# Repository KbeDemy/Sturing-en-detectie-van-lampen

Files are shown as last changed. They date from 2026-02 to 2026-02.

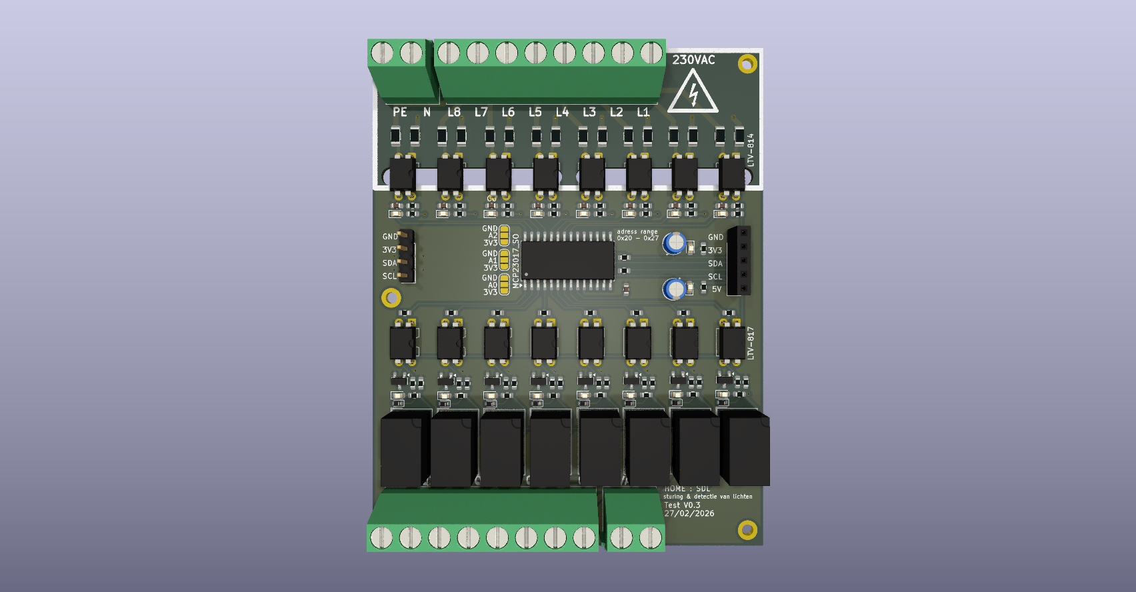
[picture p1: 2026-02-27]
documentation/screenshots/Schermafbeelding 2026-02-27 190239.png

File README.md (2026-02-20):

# I2C Uitbreiding bord - Lamp sturing & Detectie

Expansion board voor lampenbeheer. Bedoeld voor gebruik met een externe microcontroller (ESP32) via I2C.

## Specificaties
- **I/O Expander:** MCP23017 (I2C) 
- **Input:** 230V AC detectie via LTV-814 optocouplers.
- **Output:** 30V AC sturing voor Eltako relais via Omron G5V-1 relais.
- **Indicatie:** Debug-LED's voor logica en relaisstatus.

## Pinout & Adressen
- **I2C Adres:** Standaard 0x20 (instelbaar via A0, A1, A2).
- **Signaal/voeding - niveaus:** 
    - 3.3VDC logic
    - 5VDC aansturen relais
    - 30VAC aansturen eltako
    - 230VAC uitlezen status lamp
- **MCP GPA 0-7:** INPUT
- **MCP GPB 0-7:** OUTPUT

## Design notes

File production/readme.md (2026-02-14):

# Productiebestanden (JLCPCB)

* **Base Material:** FR-4
* **Layers:** 2
* **PCB Thickness:** 1.6 mm
* **Copper Weight:** 1 oz
* **Surface Finish:** HASL (met lood)

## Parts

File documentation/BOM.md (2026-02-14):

# Bill of Materials (BOM)

Hieronder staat de lijst met componenten die nodig zijn voor de assemblage van de PCB. De LCSC-codes verwijzen direct naar de onderdelen om ze makkelijk te bestellen.

| Onderdeel | Waarde / Beschrijving | Behuizing | LCSC Code | Datasheet |
| :--- | :--- | :--- | :--- | :--- |
| **IC's & Actief** | | | | |
| MCP23017-E/SO | I/O Expander 16-bit I2C | SOIC-28 | `C47023` | [PDF](https://www.lcsc.com/datasheet/C47023.pdf) |
| MMBT5551 | NPN Transistor (High Voltage) | SOT-23 | `C2977363` | [PDF](https://www.lcsc.com/datasheet/C2977363.pdf) |
| LTV-817-B | Optoisolator 5kV 1-Channel | DIP-4 | `C479627` | [PDF](https://www.lcsc.com/datasheet/C479627.pdf) |
| Phototransistor | Output 5kVrms 1 Channel | DIP-4 | `C10790` | [PDF](https://www.lcsc.com/datasheet/C10790.pdf) |
| **Relais & Connectoren** | | | | |
| G5V-1-DC5 | Relais SPDT 5V DC | THT | `C28695` | [PDF](https://www.lcsc.com/datasheet/C28695.pdf) |
| Screw Terminal | 2-Pin 5.08mm Horizontal | THT | `C480516` | [PDF](https://www.lcsc.com/datasheet/C480516.pdf) |
| Screw Terminal | 8-Pin 5.08mm Horizontal | THT | `C7165039` | [PDF](https://www.lcsc.com/datasheet/C7165039.pdf) |
| **Diodes & LEDs** | | | | |
| 1N4148WT | Schakeldiode 75V 150mA | SOD-523 | `C917006` | [PDF](https://www.lcsc.com/datasheet/C917006.pdf) |
| XL-1608SURC-06 | LED Rood 625nm | 0603 | `C965799` | [PDF](https://www.lcsc.com/datasheet/C965799.pdf) |
| **Condensatoren** | | | | |
| 100nF (0.1µF) | 50V X7R ±10% | 0603 | `C14663` | [PDF](https://www.lcsc.com/datasheet/C14663.pdf) |
| 470nF (0.47µF) | 50V X7R ±10% | 0603 | `C513577` | [PDF](https://www.lcsc.com/datasheet/C513577.pdf) |
| **Weerstanden** | | | | |
| 470Ω | ±1% 100mW | 0603 | `C23179` | [PDF](https://www.lcsc.com/datasheet/C23179.pdf) |
| 1kΩ | ±1% 100mW | 0603 | `C22548` | [PDF](https://www.lcsc.com/datasheet/C22548.pdf) |
| 4.7kΩ | ±5% 100mW | 0603 | `C2907166` | [PDF](https://www.lcsc.com/datasheet/C2907166.pdf) |
| 10kΩ | ±1% 100mW | 0603 | `C98220` | [PDF](https://www.lcsc.com/datasheet/C98220.pdf) |
| 100kΩ (HV) | 200V 500mW (Let op: Groot formaat!) | **1206** | `C309584` | [PDF](https://www.lcsc.com/datasheet/C309584.pdf) |

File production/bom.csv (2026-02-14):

Designator | Footprint | Quantity | Value | LCSC Part #
C1, C2, C3, C4, C5, C6, C7, C8 | 0603 | 8 | 0.47µ | CC0603KRX7R9BB474
C10, C11 | CP_Radial_D4.0mm_P1.50mm | 2 | 100µF
C100 | 0603 | 1 | 0.1µ | CC0603KRX7R9BB104
D1, D10, D11, D13, D15, D17, D19, D2, D21, D23, D25, D26, D3, D4, D5, D6, D7, D8 | 0603 | 18 | LED | XL-1608SURC-06
D12, D14, D16, D18, D20, D22, D24, D9 | D_SOD-523 | 8 | 1N4148 | 1N4148WT
GITHUB | https___github.com_KbeDemy_Sturing-en-detectie-van-lampen | 1 | DOCS
J0 | PinSocket_1x05_P2.54mm_Vertical | 1 | Conn_01x05
J1, J4 | TerminalBlock_Phoenix_MKDS-1,5-2-5.08_1x02_P5.08mm_Horizontal | 2 | Screw_Terminal_01x02 | 1715721
J2, J3 | TerminalBlock_Phoenix_MKDS-1,5-8-5.08_1x08_P5.08mm_Horizontal | 2 | Screw_Terminal_01x08 | 1715789
J5 | PinHeader_1x04_P2.54mm_Vertical | 1 | Conn_01x04
K1, K2, K3, K4, K5, K6, K7, K8 | Relay_SPDT_Omron_G5V-1 | 8 | G5V-1 | G5V-1-DC5
Q1, Q2, Q3, Q4, Q5, Q6, Q7, Q8 | SOT-23 | 8 | NPN | MMBT5551
R1, R10, R13, R14, R17, R18, R2, R21, R22, R25, R26, R29, R30, R5, R6, R9 | 1206 | 16 | 100k | RC1206FR-7W100KL
R11, R15, R19, R23, R27, R3, R31, R34, R40, R44, R48, R52, R56, R60, R64, R7 | 0603 | 16 | 10k | RC0603FR-0710KL
R12, R16, R20, R24, R28, R32, R35, R36, R37, R38, R4, R41, R42, R45, R46, R49, R50, R53, R54, R57, R58, R61, R62, R66, R67, R8 | 0603 | 26 | 470 | 0603WAF4700T5E
R33, R39, R43, R47, R51, R55, R59, R63 | 0603 | 8 | 1k | RC0603FR-071KL
R65, R68 | 0603 | 2 | 4.7k | FRC0603J472 TS
U1, U3, U4, U6, U7, U8, U9 | DIP-4_W7.62mm | 7 | LTV-814 | LITEON LTV-814
U11, U12, U13, U14, U15, U16, U17, U18 | DIP-4_W7.62mm | 8 | LTV-817 | LTV-817-B
U2 | SOIC-28W_7.5x17.9mm_P1.27mm | 1 | MCP23017_SO | MCP23017-E/SO
U5 | DIP-4_W7.62mm | 1 | LTV-814

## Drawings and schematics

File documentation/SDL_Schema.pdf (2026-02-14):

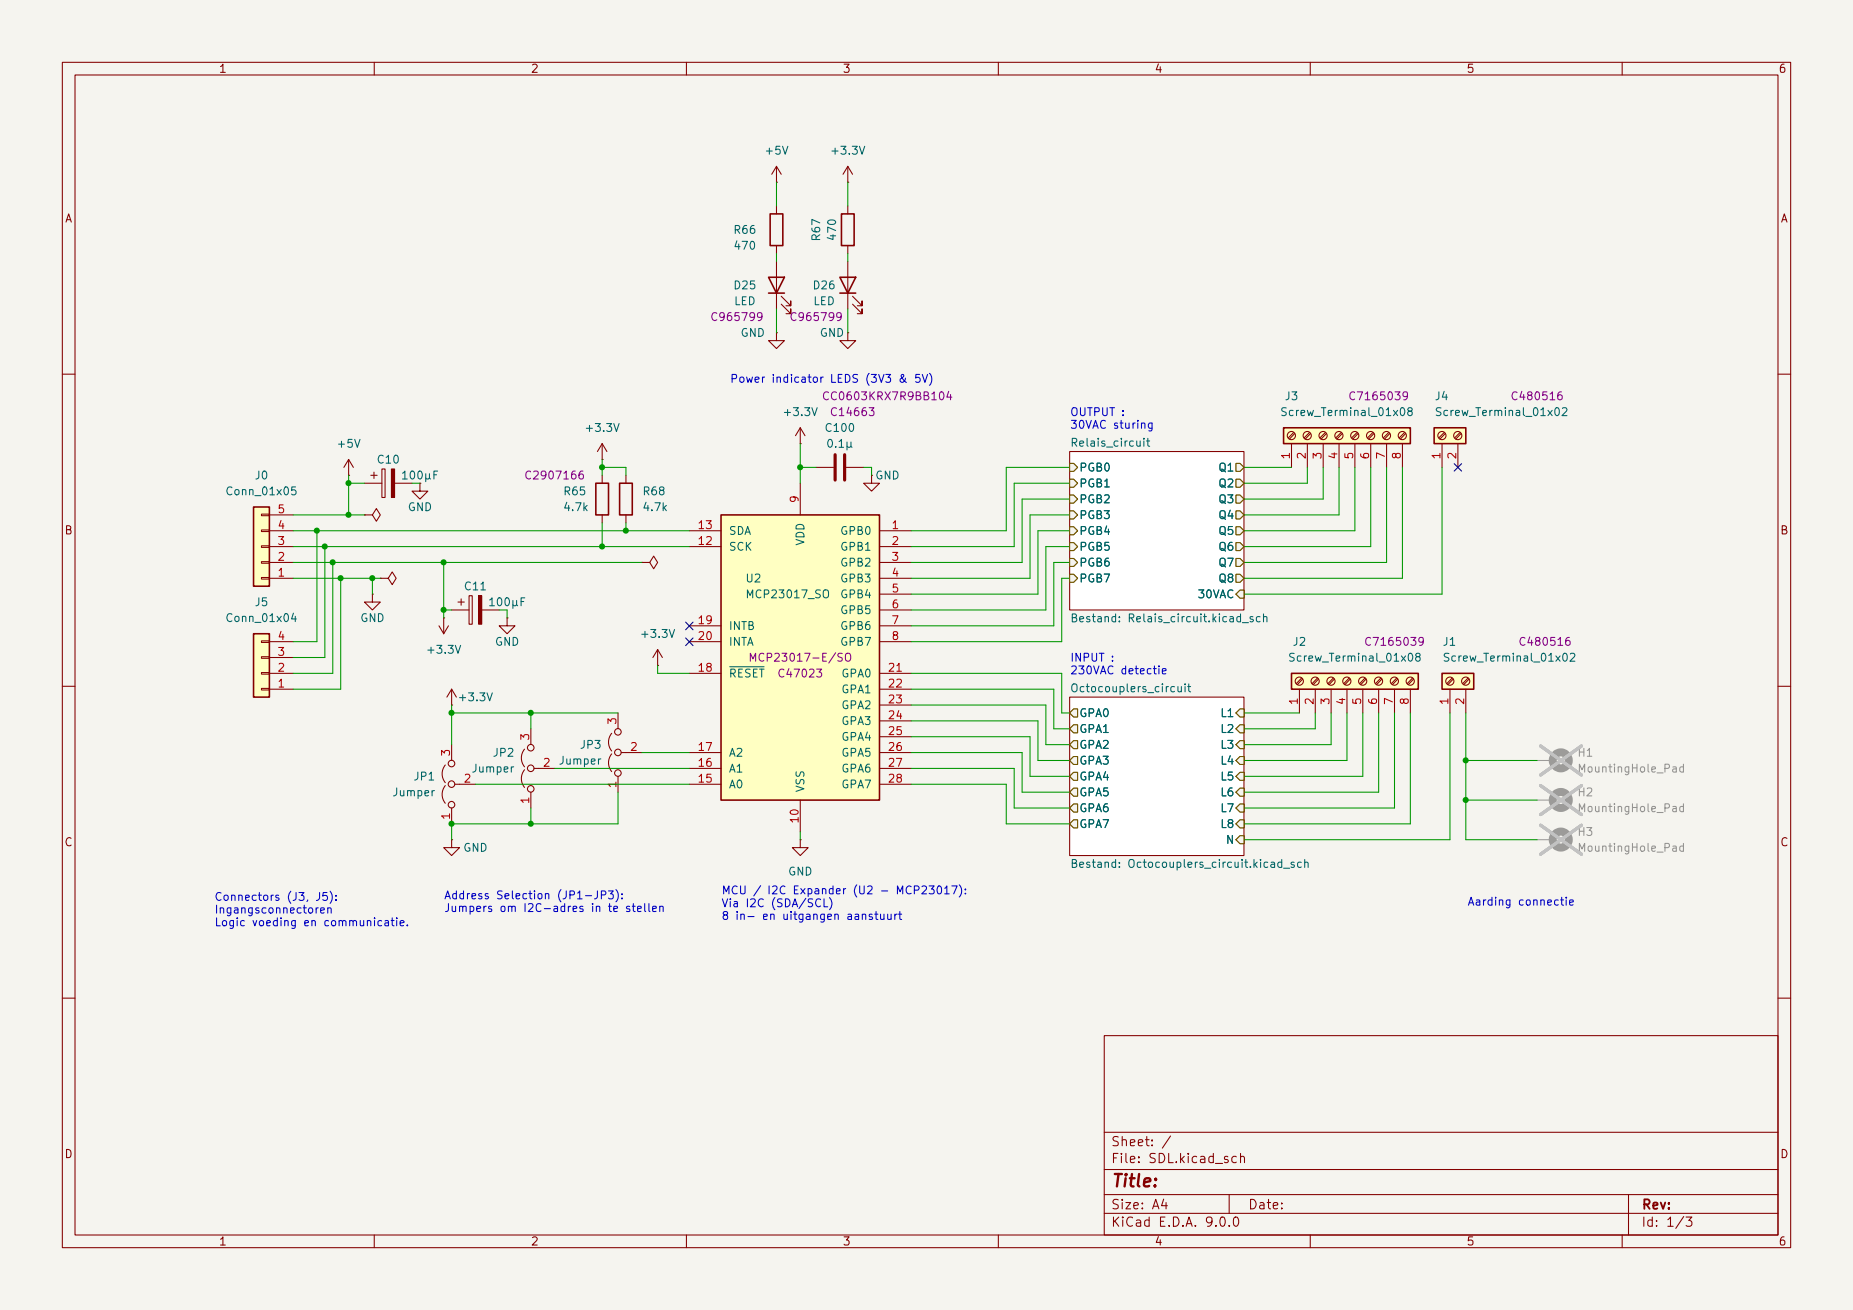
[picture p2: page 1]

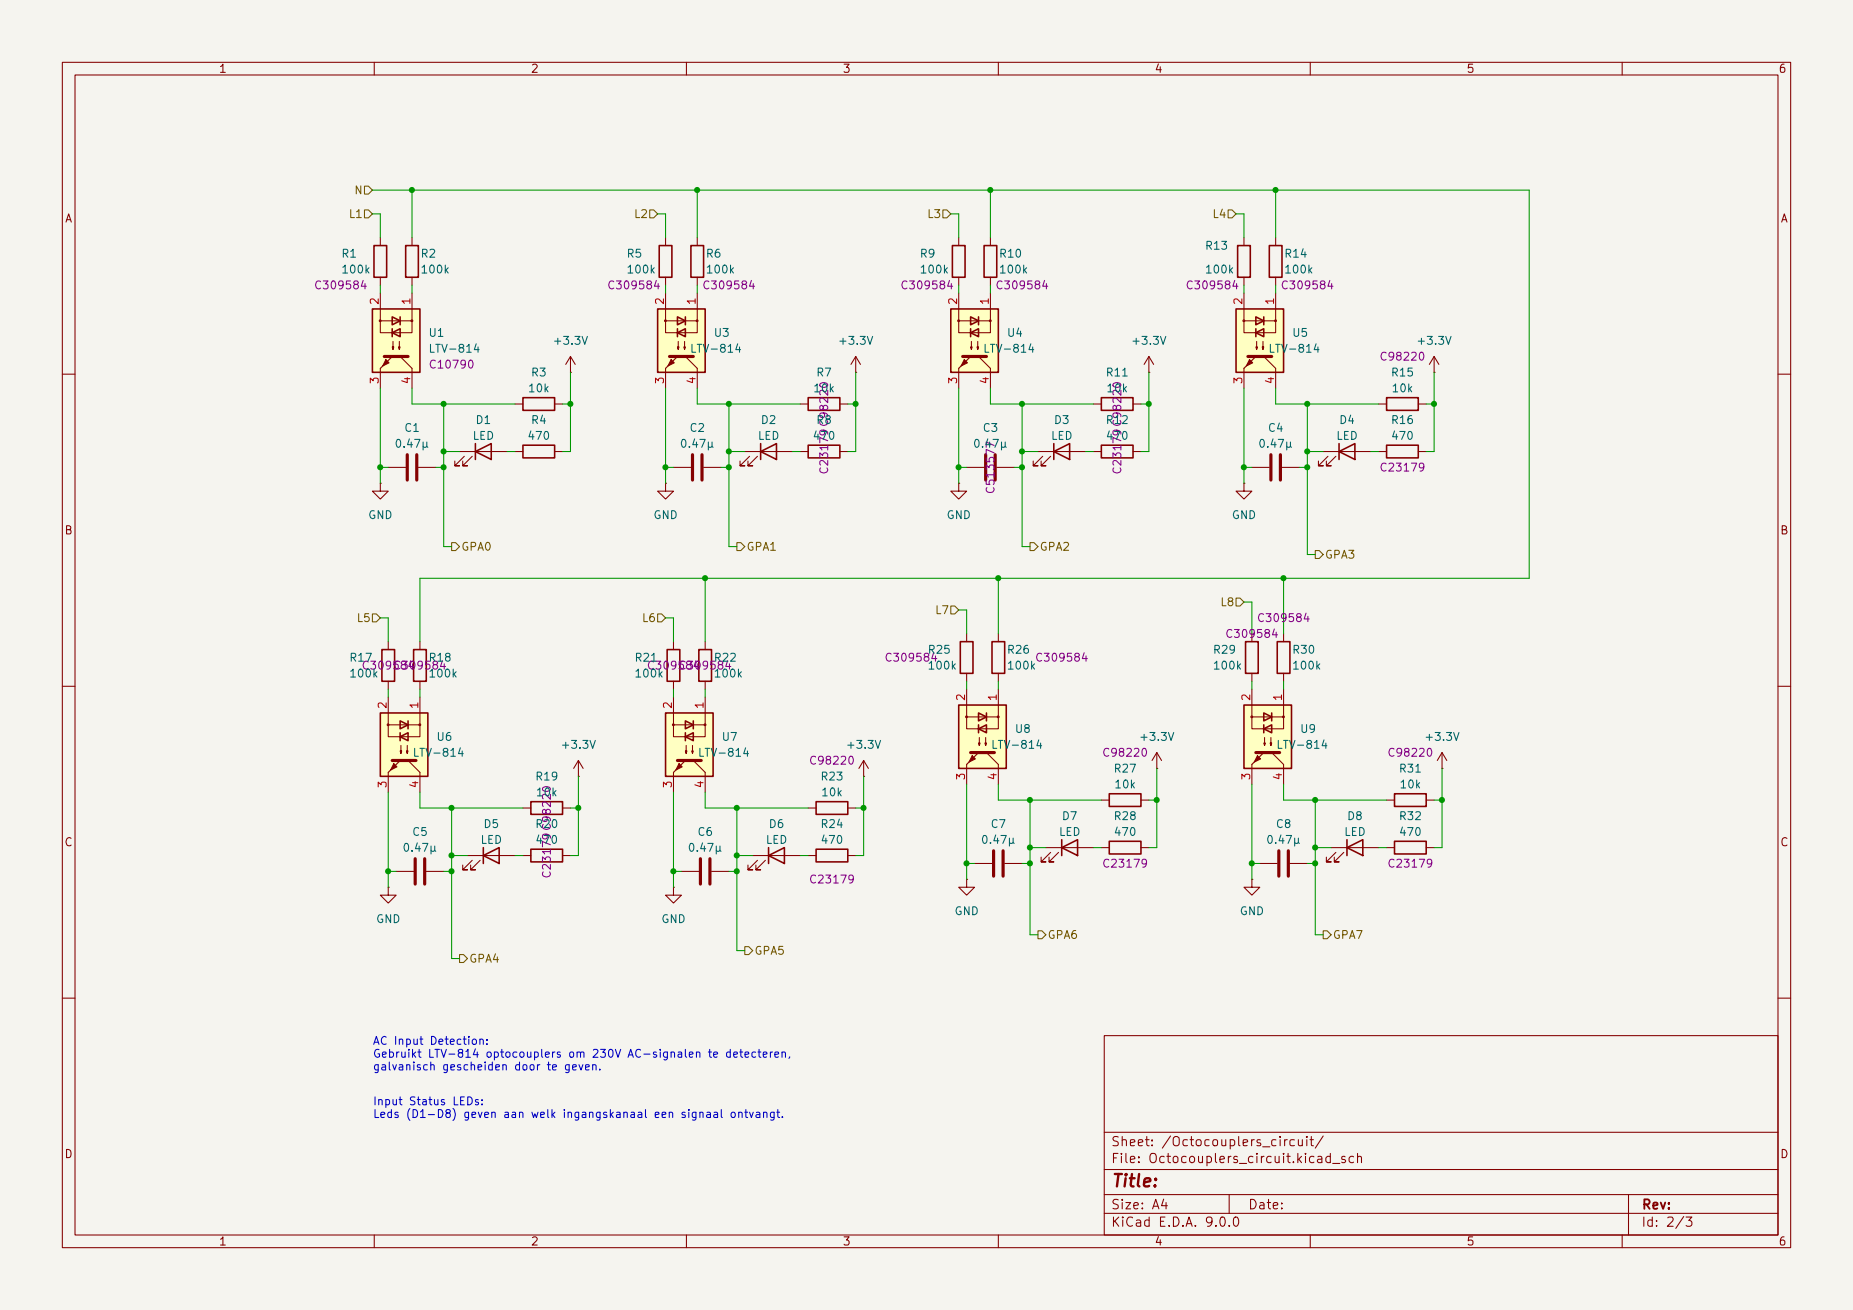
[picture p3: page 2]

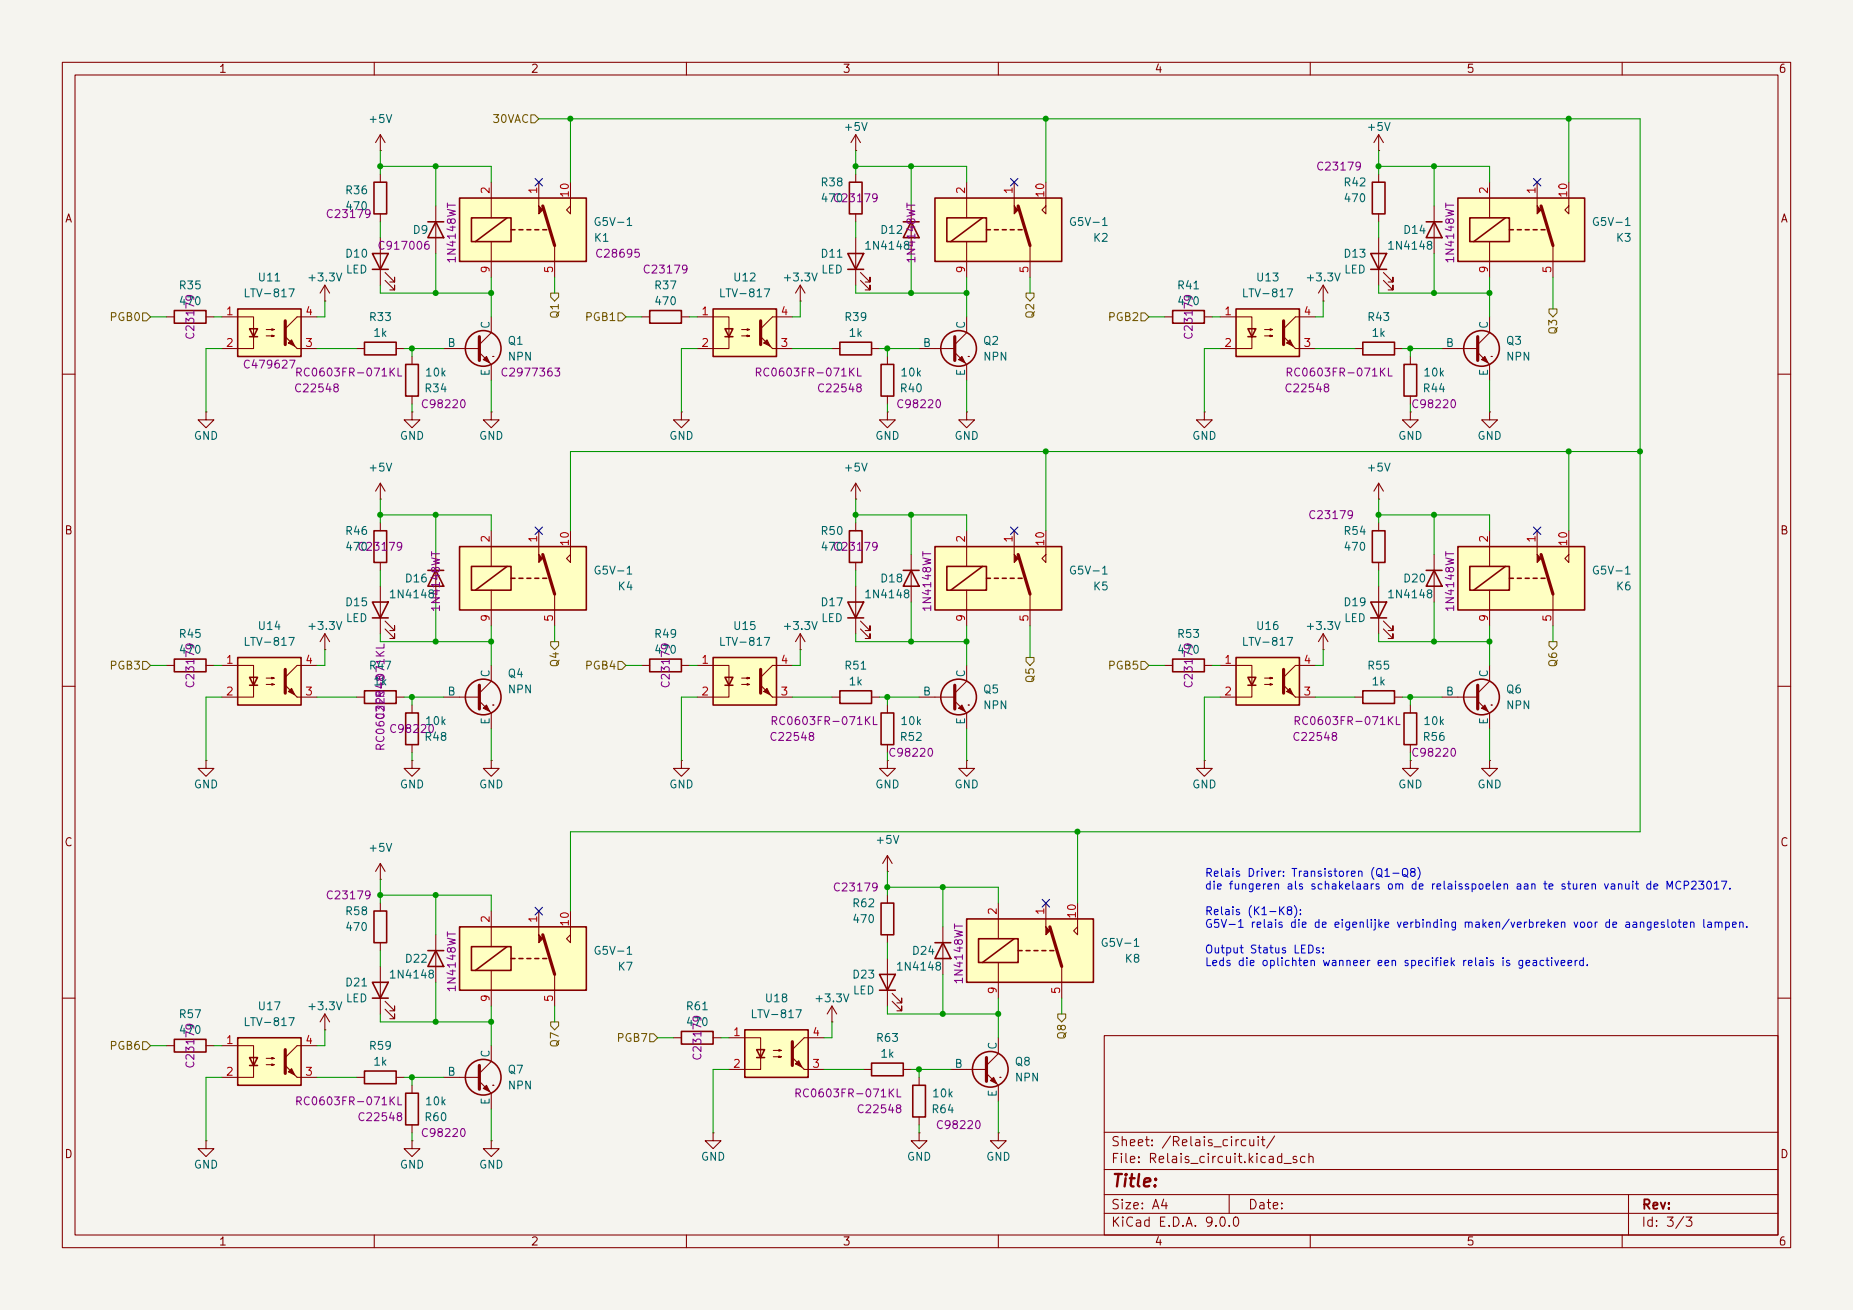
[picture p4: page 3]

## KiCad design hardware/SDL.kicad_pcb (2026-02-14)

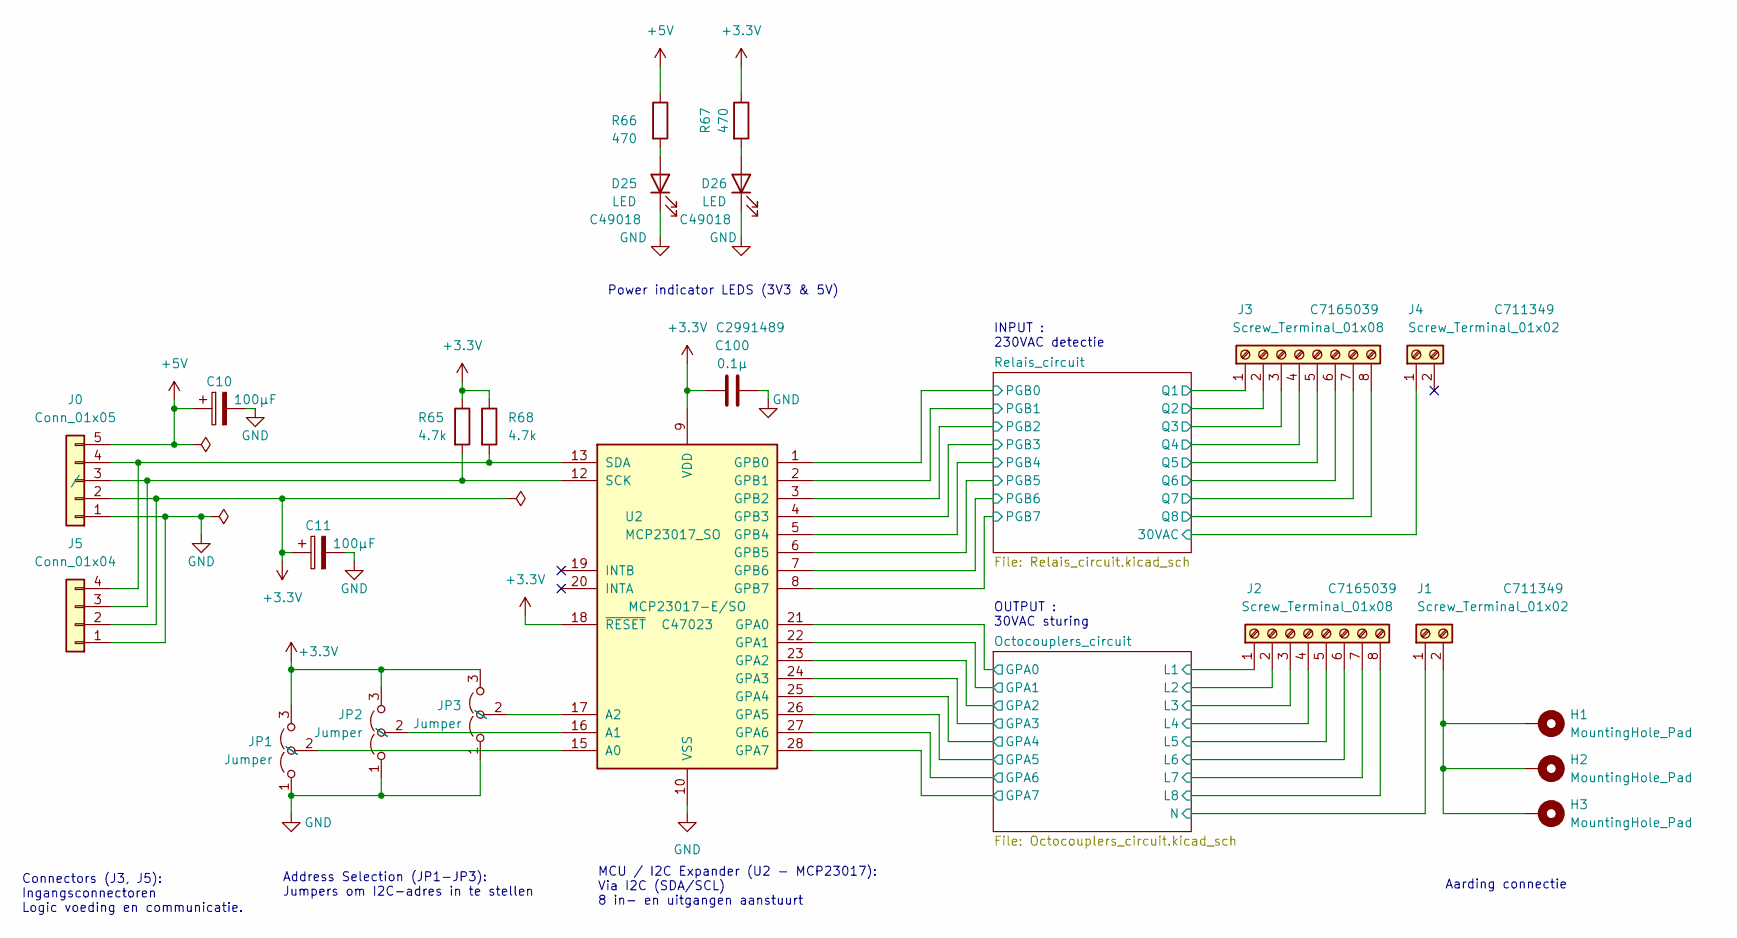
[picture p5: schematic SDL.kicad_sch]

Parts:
C10, C11: 100µF; CP_Radial_D4.0mm_P1.50mm
C100: 0.1µ; C_0603_1608Metric; JLCPCB C2991489
D25, D26: LED; LED_0603_1608Metric; JLCPCB C49018
H1, H2, H3: MountingHole_Pad; MountingHole_2.2mm_M2_DIN965_Pad_TopBottom
J0: Conn_01x05; PinSocket_1x05_P2.54mm_Vertical; MPN /; JLCPCB /
J1, J4: Screw_Terminal_01x02; TerminalBlock_Phoenix_MKDS-1,5-2-5.08_1x02_P5.08mm_Horizont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; MPN 1715721; JLCPCB C711349
J2, J3: Screw_Terminal_01x08; TerminalBlock_Phoenix_MKDS-1,5-8-5.08_1x08_P5.08mm_Horizont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; MPN 1715789; JLCPCB C7165039
J5: Conn_01x04; PinHeader_1x04_P2.54mm_Vertical
JP1, JP2, JP3: Jumper; SolderJumper-3_P1.3mm_Open_RoundedPad1.0x1.5mm_NumberLabels; MPN /; JLCPCB /
R65, R68: 4.7k; R_0603_1608Metric
R66, R67: 470; R_0603_1608Metric
U2: MCP23017_SO; SOIC-28W_7.5x17.9mm_P1.27mm; MPN MCP23017-E/SO; JLCPCB C47023

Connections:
+3.3V: C11.1, C100.1, J0.2, J5.2, JP1.3 (B), JP2.3 (B), JP3.3 (B), R65.1, R67.1, R68.1, U2.9 (VDD), U2.18 (~RESET); also elsewhere on the board
+5V: C10.1, J0.5, R66.1; also elsewhere on the board
/Octocouplers_circuit/GPA0: U2.21 (GPA0); also elsewhere on the board
/Octocouplers_circuit/GPA1: U2.22 (GPA1); also elsewhere on the board
/Octocouplers_circuit/GPA2: U2.23 (GPA2); also elsewhere on the board
/Octocouplers_circuit/GPA3: U2.24 (GPA3); also elsewhere on the board
/Octocouplers_circuit/GPA4: U2.25 (GPA4); also elsewhere on the board
/Octocouplers_circuit/GPA5: U2.26 (GPA5); also elsewhere on the board
/Octocouplers_circuit/GPA6: U2.27 (GPA6); also elsewhere on the board
/Octocouplers_circuit/GPA7: U2.28 (GPA7); also elsewhere on the board
/Octocouplers_circuit/L1: J2.1; also elsewhere on the board
/Octocouplers_circuit/L2: J2.2; also elsewhere on the board
/Octocouplers_circuit/L3: J2.3; also elsewhere on the board
/Octocouplers_circuit/L4: J2.4; also elsewhere on the board
/Octocouplers_circuit/L5: J2.5; also elsewhere on the board
/Octocouplers_circuit/L6: J2.6; also elsewhere on the board
/Octocouplers_circuit/L7: J2.7; also elsewhere on the board
/Octocouplers_circuit/L8: J2.8; also elsewhere on the board
/Octocouplers_circuit/N: J1.1; also elsewhere on the board
/Relais_circuit/30VAC: J4.1; also elsewhere on the board
/Relais_circuit/PGB0: U2.1 (GPB0); also elsewhere on the board
/Relais_circuit/PGB1: U2.2 (GPB1); also elsewhere on the board
/Relais_circuit/PGB2: U2.3 (GPB2); also elsewhere on the board
/Relais_circuit/PGB3: U2.4 (GPB3); also elsewhere on the board
/Relais_circuit/PGB4: U2.5 (GPB4); also elsewhere on the board
/Relais_circuit/PGB5: U2.6 (GPB5); also elsewhere on the board
/Relais_circuit/PGB6: U2.7 (GPB6); also elsewhere on the board
/Relais_circuit/PGB7: U2.8 (GPB7); also elsewhere on the board
/Relais_circuit/Q1: J3.1; also elsewhere on the board
/Relais_circuit/Q2: J3.2; also elsewhere on the board
/Relais_circuit/Q3: J3.3; also elsewhere on the board
/Relais_circuit/Q4: J3.4; also elsewhere on the board
/Relais_circuit/Q5: J3.5; also elsewhere on the board
/Relais_circuit/Q6: J3.6; also elsewhere on the board
/Relais_circuit/Q7: J3.7; also elsewhere on the board
/Relais_circuit/Q8: J3.8; also elsewhere on the board
GND: C10.2, C11.2, C100.2, D25.1 (K), D26.1 (K), J0.1, J5.1, JP1.1 (A), JP2.1 (A), JP3.1 (A), U2.10 (VSS); also elsewhere on the board
unnamed: D25.2 (A), R66.2
unnamed: D26.2 (A), R67.2
unnamed: J0.3, J5.3, R65.2, U2.12 (SCK)
unnamed: J0.4, J5.4, R68.2, U2.13 (SDA)
unnamed: H1.1, H2.1, H3.1, J1.2
unnamed: JP1.2 (C), U2.15 (A0)
unnamed: JP2.2 (C), U2.16 (A1)
unnamed: JP3.2 (C), U2.17 (A2)

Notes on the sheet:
INPUT : 230VAC detectie
OUTPUT : 30VAC sturing
MCU / I2C Expander (U2 - MCP23017): Via I2C (SDA/SCL) 8 in- en uitgangen aanstuurt
Connectors (J3, J5): Ingangsconnectoren Logic voeding en communicatie.
Address Selection (JP1-JP3): Jumpers om I2C-adres in te stellen
Aarding connectie
Power indicator LEDS (3V3 & 5V)

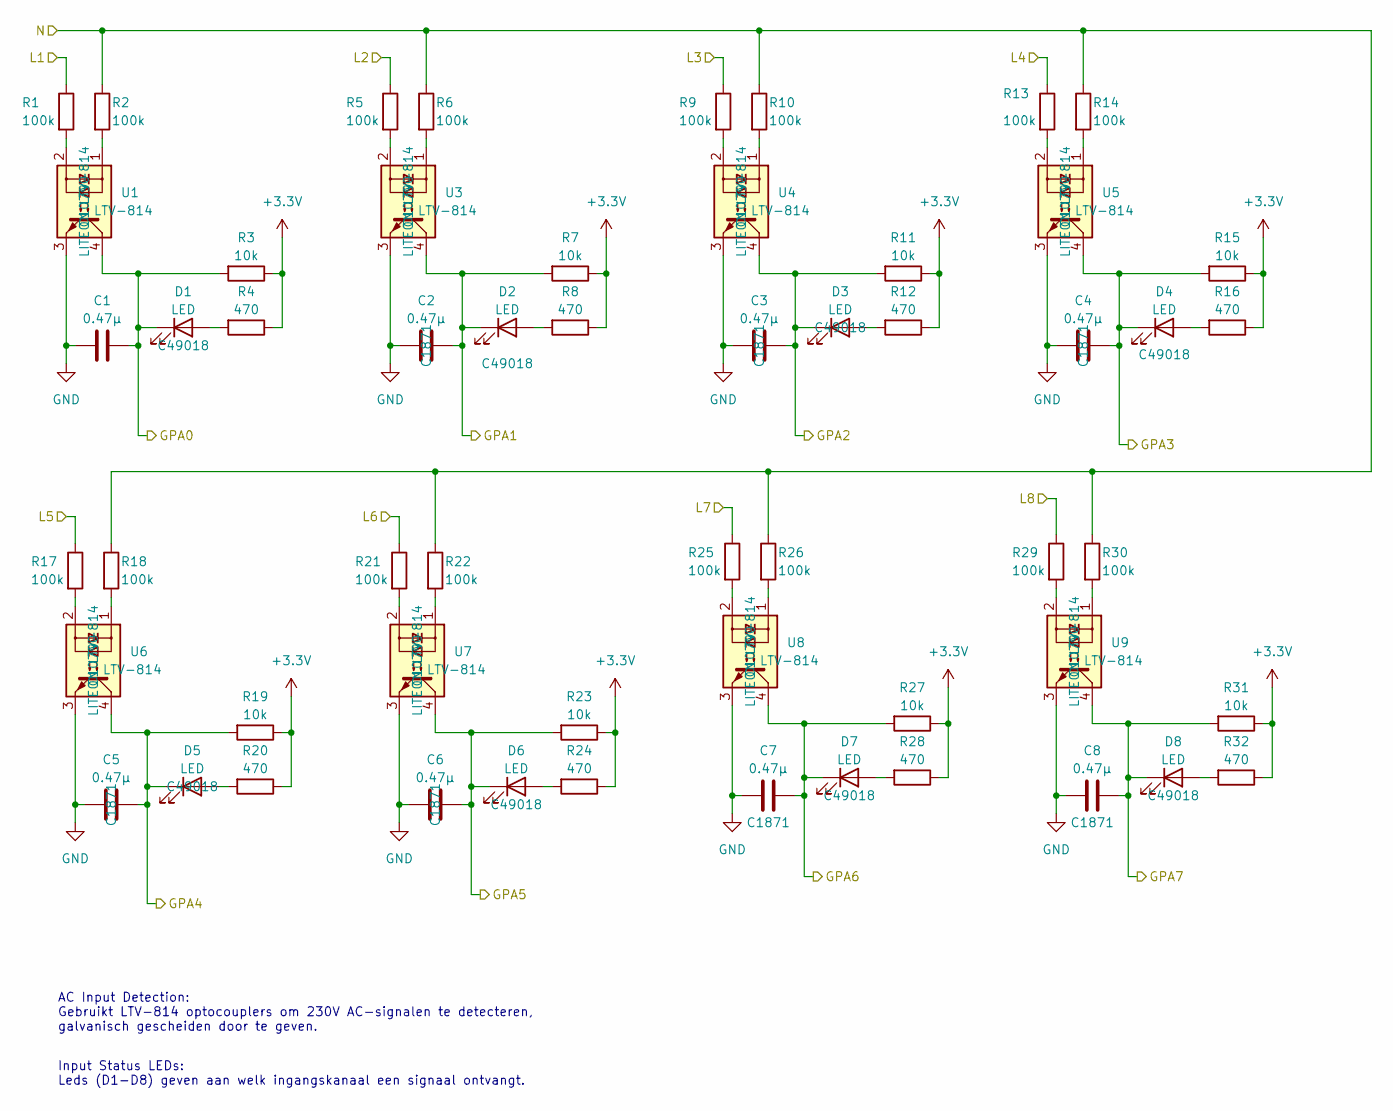
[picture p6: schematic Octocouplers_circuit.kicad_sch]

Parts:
C1, C2, C3, C4, C5, C6, C7, C8: 0.47µ; C_0603_1608Metric; JLCPCB C1871
D1, D2, D3, D4, D5, D6, D7, D8: LED; LED_0603_1608Metric; JLCPCB C49018
R1, R2, R5, R6, R9, R10, R13, R14, R17, R18, R21, R22, R25, R26, R29, R30: 100k; R_1206_3216Metric
R3, R7, R11, R15, R19, R23, R27, R31: 10k; R_0603_1608Metric
R4, R8, R12, R16, R20, R24, R28, R32: 470; R_0603_1608Metric
U1, U3, U4, U5, U6, U7, U8, U9: LTV-814; DIP-4_W7.62mm; MPN LITEON LTV-814; JLCPCB C10790

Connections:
+3.3V: R3.1, R4.1, R7.1, R8.1, R11.1, R12.1, R15.1, R16.1, R19.1, R20.1, R23.1, R24.1, R27.1, R28.1, R31.1, R32.1; also elsewhere on the board
/Octocouplers_circuit/GPA0: C1.2, D1.1 (K), R3.2, U1.4; also elsewhere on the board
/Octocouplers_circuit/GPA1: C2.2, D2.1 (K), R7.2, U3.4; also elsewhere on the board
/Octocouplers_circuit/GPA2: C3.2, D3.1 (K), R11.2, U4.4; also elsewhere on the board
/Octocouplers_circuit/GPA3: C4.2, D4.1 (K), R15.2, U5.4; also elsewhere on the board
/Octocouplers_circuit/GPA4: C5.2, D5.1 (K), R19.2, U6.4; also elsewhere on the board
/Octocouplers_circuit/GPA5: C6.2, D6.1 (K), R23.2, U7.4; also elsewhere on the board
/Octocouplers_circuit/GPA6: C7.2, D7.1 (K), R27.2, U8.4; also elsewhere on the board
/Octocouplers_circuit/GPA7: C8.2, D8.1 (K), R31.2, U9.4; also elsewhere on the board
/Octocouplers_circuit/L1: R1.1; also elsewhere on the board
/Octocouplers_circuit/L2: R5.1; also elsewhere on the board
/Octocouplers_circuit/L3: R9.1; also elsewhere on the board
/Octocouplers_circuit/L4: R13.1; also elsewhere on the board
/Octocouplers_circuit/L5: R17.1; also elsewhere on the board
/Octocouplers_circuit/L6: R21.1; also elsewhere on the board
/Octocouplers_circuit/L7: R25.1; also elsewhere on the board
/Octocouplers_circuit/L8: R29.1; also elsewhere on the board
/Octocouplers_circuit/N: R2.1, R6.1, R10.1, R14.1, R18.1, R22.1, R26.1, R30.1; also elsewhere on the board
GND: C1.1, C2.1, C3.1, C4.1, C5.1, C6.1, C7.1, C8.1, U1.3, U3.3, U4.3, U5.3, U6.3, U7.3, U8.3, U9.3; also elsewhere on the board
unnamed: D1.2 (A), R4.2
unnamed: D2.2 (A), R8.2
unnamed: D3.2 (A), R12.2
unnamed: D4.2 (A), R16.2
unnamed: D5.2 (A), R20.2
unnamed: D6.2 (A), R24.2
unnamed: D7.2 (A), R28.2
unnamed: D8.2 (A), R32.2
unnamed: R1.2, U1.2
unnamed: R2.2, U1.1
unnamed: R5.2, U3.2
unnamed: R6.2, U3.1
unnamed: R9.2, U4.2
unnamed: R10.2, U4.1
unnamed: R13.2, U5.2
unnamed: R14.2, U5.1
unnamed: R17.2, U6.2
unnamed: R18.2, U6.1
unnamed: R21.2, U7.2
unnamed: R22.2, U7.1
unnamed: R25.2, U8.2
unnamed: R26.2, U8.1
unnamed: R29.2, U9.2
unnamed: R30.2, U9.1

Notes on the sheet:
AC Input Detection: Gebruikt LTV-814 optocouplers om 230V AC-signalen te detecteren, galvanisch gescheiden door te geven.
Input Status LEDs: Leds (D1-D8) geven aan welk ingangskanaal een signaal ontvangt.

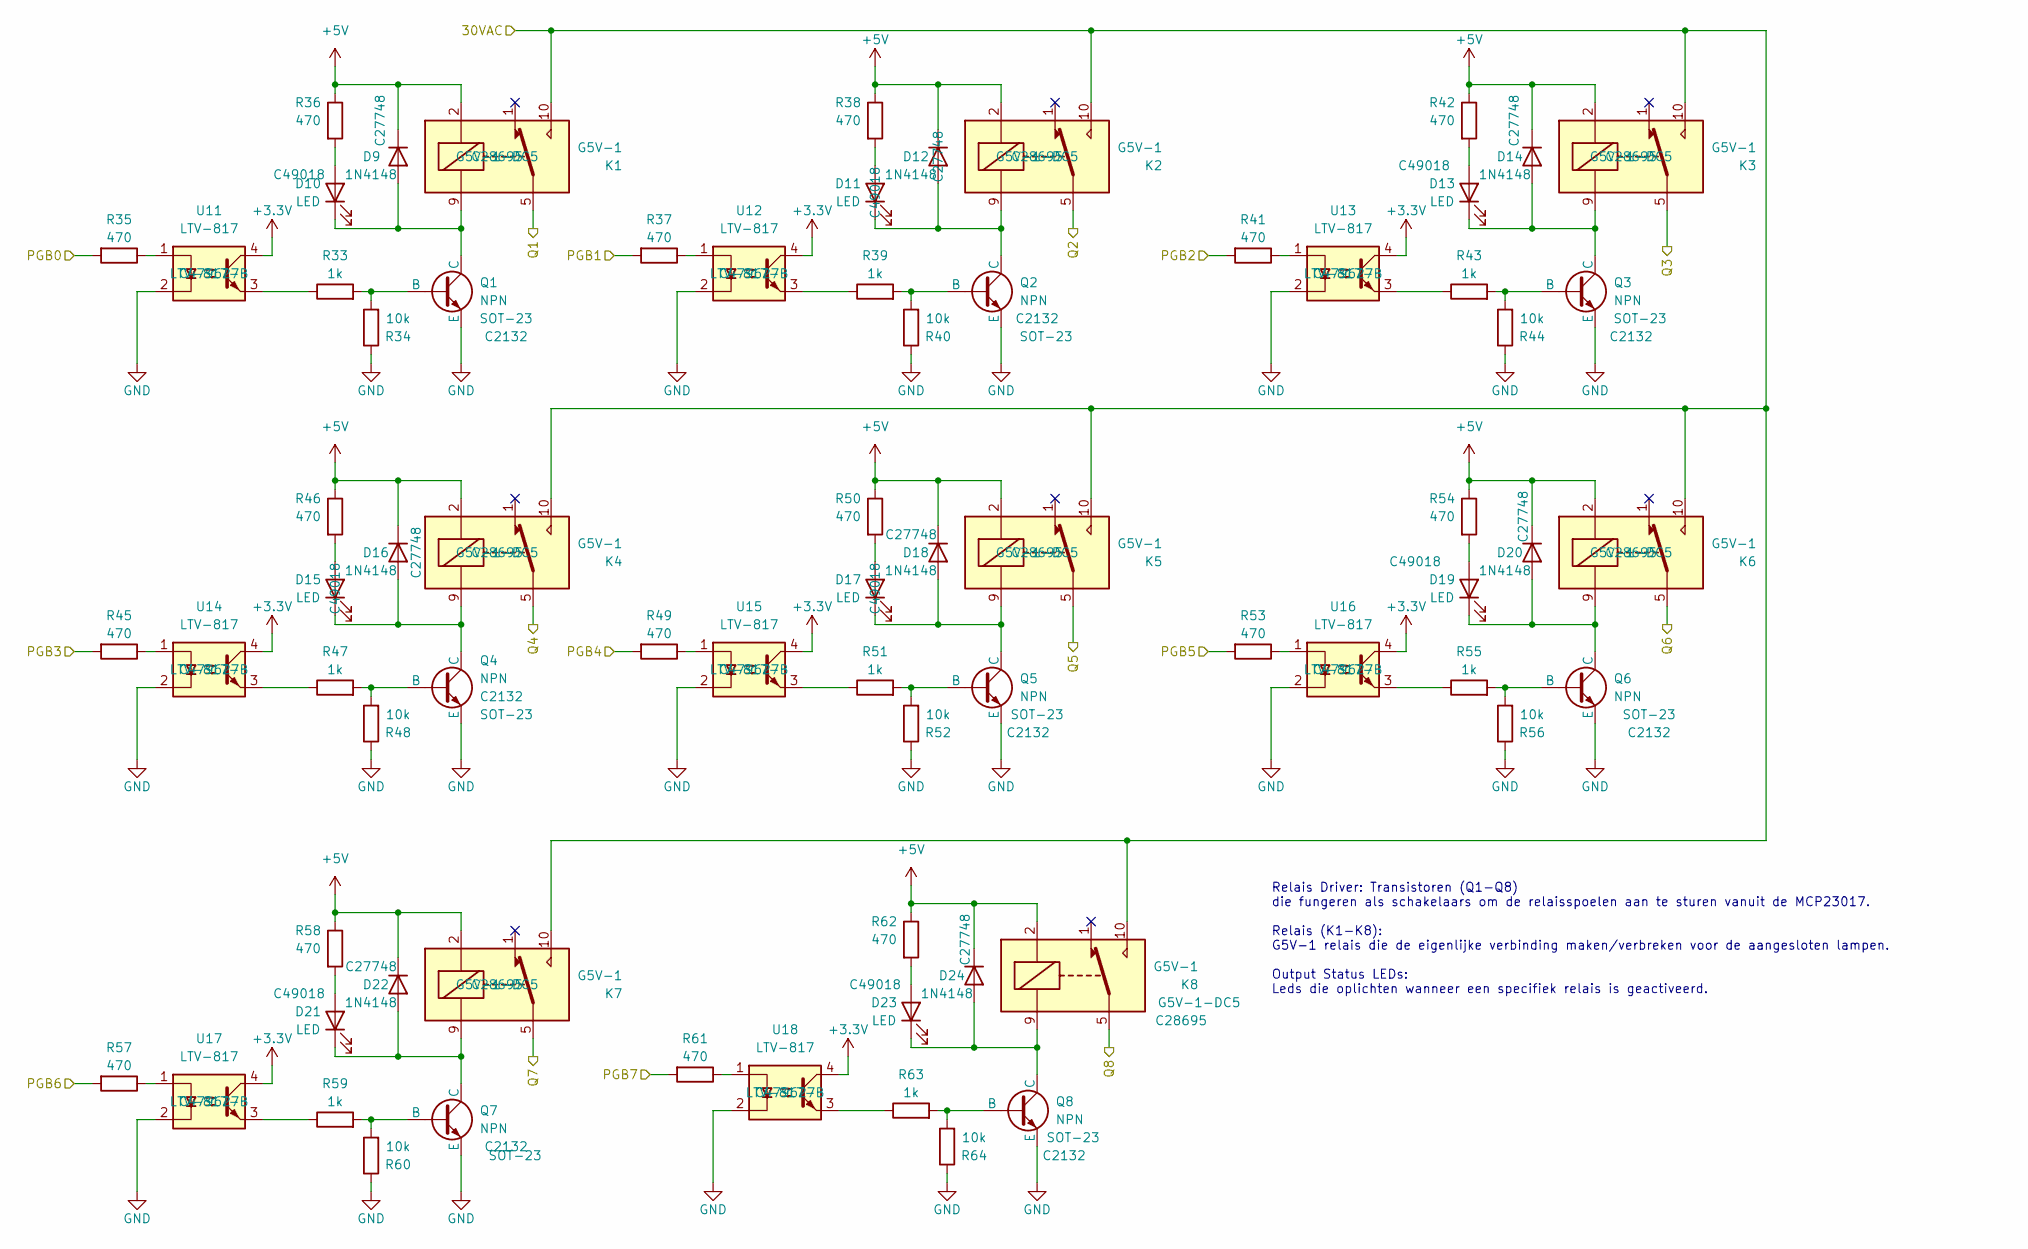
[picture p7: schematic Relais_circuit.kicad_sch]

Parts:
D9, D12, D14, D16, D18, D20, D22, D24: 1N4148; D_SOD-523; JLCPCB C27748
D10, D11, D13, D15, D17, D19, D21, D23: LED; LED_0603_1608Metric; JLCPCB C49018
K1, K2, K3, K4, K5, K6, K7, K8: G5V-1; Relay_SPDT_Omron_G5V-1; MPN G5V-1-DC5; JLCPCB C28695
Q1, Q2, Q3, Q4, Q5, Q6, Q7, Q8: NPN; SOT-23; MPN SOT-23; JLCPCB C2132
R33, R39, R43, R47, R51, R55, R59, R63: 1k; R_0603_1608Metric
R34, R40, R44, R48, R52, R56, R60, R64: 10k; R_0603_1608Metric
R35, R36, R37, R38, R41, R42, R45, R46, R49, R50, R53, R54, R57, R58, R61, R62: 470; R_0603_1608Metric
U11, U12, U13, U14, U15, U16, U17, U18: LTV-817; DIP-4_W7.62mm; MPN LTV-817-B; JLCPCB C479627

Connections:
+3.3V: U11.4, U12.4, U13.4, U14.4, U15.4, U16.4, U17.4, U18.4; also elsewhere on the board
+5V: D9.1 (K), D12.1 (K), D14.1 (K), D16.1 (K), D18.1 (K), D20.1 (K), D22.1 (K), D24.1 (K), K1.2, K2.2, K3.2, K4.2, K5.2, K6.2, K7.2, K8.2, R36.1, R38.1, R42.1, R46.1, R50.1, R54.1, R58.1, R62.1; also elsewhere on the board
/Relais_circuit/30VAC: K1.10, K2.10, K3.10, K4.10, K5.10, K6.10, K7.10, K8.10; also elsewhere on the board
/Relais_circuit/PGB0: R35.2; also elsewhere on the board
/Relais_circuit/PGB1: R37.2; also elsewhere on the board
/Relais_circuit/PGB2: R41.2; also elsewhere on the board
/Relais_circuit/PGB3: R45.2; also elsewhere on the board
/Relais_circuit/PGB4: R49.2; also elsewhere on the board
/Relais_circuit/PGB5: R53.2; also elsewhere on the board
/Relais_circuit/PGB6: R57.2; also elsewhere on the board
/Relais_circuit/PGB7: R61.2; also elsewhere on the board
/Relais_circuit/Q1: K1.5, K1.6; also elsewhere on the board
/Relais_circuit/Q2: K2.5, K2.6; also elsewhere on the board
/Relais_circuit/Q3: K3.5, K3.6; also elsewhere on the board
/Relais_circuit/Q4: K4.5, K4.6; also elsewhere on the board
/Relais_circuit/Q5: K5.5, K5.6; also elsewhere on the board
/Relais_circuit/Q6: K6.5, K6.6; also elsewhere on the board
/Relais_circuit/Q7: K7.5, K7.6; also elsewhere on the board
/Relais_circuit/Q8: K8.5, K8.6; also elsewhere on the board
GND: Q1.2 (E), Q2.2 (E), Q3.2 (E), Q4.2 (E), Q5.2 (E), Q6.2 (E), Q7.2 (E), Q8.2 (E), R34.1, R40.1, R44.1, R48.1, R52.1, R56.1, R60.1, R64.1, U11.2, U12.2, U13.2, U14.2, U15.2, U16.2, U17.2, U18.2; also elsewhere on the board
unnamed: D10.2 (A), R36.2
unnamed: D9.2 (A), D10.1 (K), K1.9, Q1.3 (C)
unnamed: D11.2 (A), R38.2
unnamed: D11.1 (K), D12.2 (A), K2.9, Q2.3 (C)
unnamed: D13.2 (A), R42.2
unnamed: D13.1 (K), D14.2 (A), K3.9, Q3.3 (C)
unnamed: D15.2 (A), R46.2
unnamed: D15.1 (K), D16.2 (A), K4.9, Q4.3 (C)
unnamed: D17.2 (A), R50.2
unnamed: D17.1 (K), D18.2 (A), K5.9, Q5.3 (C)
unnamed: D19.2 (A), R54.2
unnamed: D19.1 (K), D20.2 (A), K6.9, Q6.3 (C)
unnamed: D21.2 (A), R58.2
unnamed: D21.1 (K), D22.2 (A), K7.9, Q7.3 (C)
unnamed: D23.2 (A), R62.2
unnamed: D23.1 (K), D24.2 (A), K8.9, Q8.3 (C)
unnamed: Q1.1 (B), R33.2, R34.2
unnamed: Q2.1 (B), R39.2, R40.2
unnamed: Q3.1 (B), R43.2, R44.2
unnamed: Q4.1 (B), R47.2, R48.2
unnamed: Q5.1 (B), R51.2, R52.2
unnamed: Q6.1 (B), R55.2, R56.2
unnamed: Q7.1 (B), R59.2, R60.2
unnamed: Q8.1 (B), R63.2, R64.2
unnamed: R33.1, U11.3
unnamed: R35.1, U11.1
unnamed: R37.1, U12.1
unnamed: R39.1, U12.3
unnamed: R41.1, U13.1
unnamed: R43.1, U13.3
unnamed: R45.1, U14.1
unnamed: R47.1, U14.3
unnamed: R49.1, U15.1
unnamed: R51.1, U15.3
unnamed: R53.1, U16.1
unnamed: R55.1, U16.3
unnamed: R57.1, U17.1
unnamed: R59.1, U17.3
unnamed: R61.1, U18.1
unnamed: R63.1, U18.3

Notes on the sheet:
Relais Driver: Transistoren (Q1-Q8) die fungeren als schakelaars om de relaisspoelen aan te sturen vanuit de MCP23017. Relais (K1-K8): G5V-1 relais die de eigenlijke verbinding maken/verbreken voor de aangesloten lampen. Output Status LEDs: Leds die oplichten wanneer een specifiek relais is geactiv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

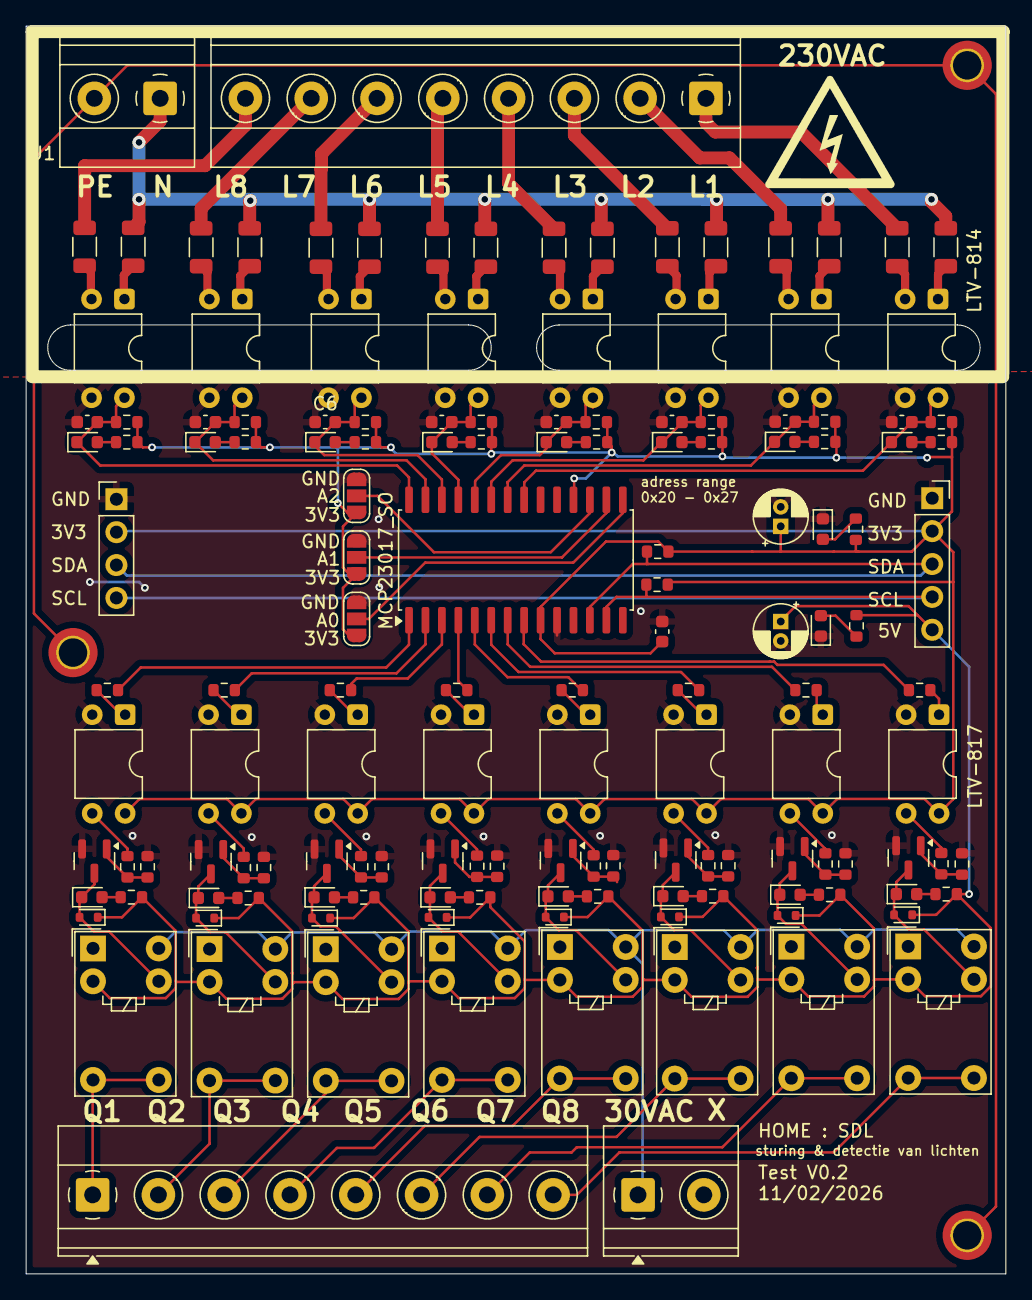
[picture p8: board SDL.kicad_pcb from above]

Board: 4 copper layers, 75.6 x 96.3 mm, 151 parts (1 on the bottom side), 109 nets.

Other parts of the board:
GITHUB: DOCS; https___github.com_KbeDemy_Sturing-en-detectie-van-lampen

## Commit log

2026-02-13 Revise README for I2C expansion board details
    Updated project title and added specifications for the I2C expansion board.
2026-02-13 Update signal/power levels section in README
2026-02-14 Add Bill of Materials section to readme
    Added a Bill of Materials (BOM) section with component details, including values, descriptions, package types, LCSC codes, and datasheets.
2026-02-14 Add PCB specifications to readme
2026-02-20 Update relay control description in README
